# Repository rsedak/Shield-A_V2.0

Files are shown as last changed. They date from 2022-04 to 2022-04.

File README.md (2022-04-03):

[Croatian version](README_HR-HR.md). 

Introduction
============

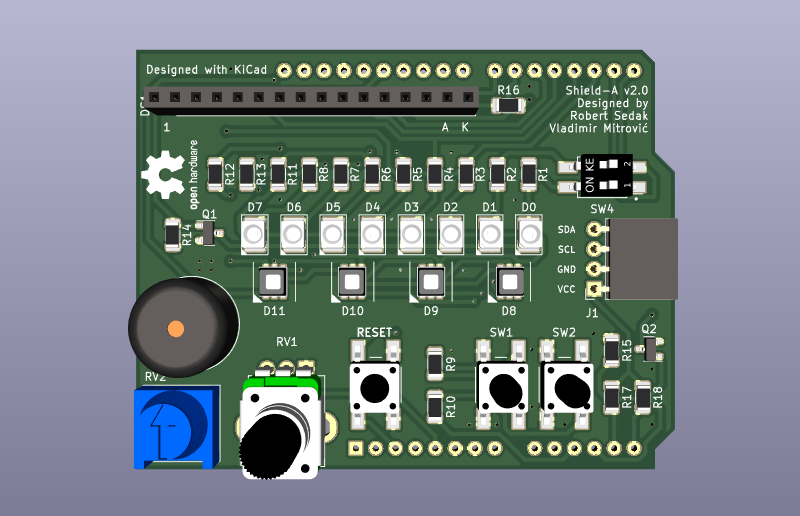
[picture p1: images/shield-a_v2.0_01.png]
Shield application

Shield-A v2.0 is version of Arduino Uno based shield for student education compatible with BASCOM-AVR(C) and Arduino IDE.
During programming please keep in mind next design rules:
- D0-D7 — LEDs can be used only if D12 is set to OUTPUT HIGH state
- LCD 1602 — can be used only if A3 is set to OUTPUT HIGH state
- RGB LED — are connected in matrix (D5-D7 - colors; D8-D11 - LEDs)
- D12 — enables D0-D7 LEDs
- D13 — reserved for buzzer
- A0 — reserved for potentiometer
- A1,A2 — reserved for switch in INPUT_PULLUP mode
- A3 — enables LCD 1602 back-light
- A4,A5 — reserved for I2C communication with on board pull-up resistors

Contributors
------------
- Vladimir Mitrović — features, BASCOM-AVR expertise
- Robert Sedak — features, Arduino expertise, schematic design, CAD design. 

Application
-----------
Robert Sedak made a video with examples programmed in Arduino IDE:

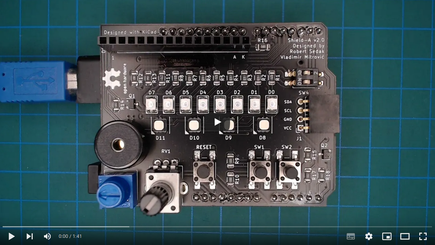
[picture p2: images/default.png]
Shield application (https://youtu.be/8LH1n_c-9tc "Shield-A examples")


You can download examples for Arduino IDE from [here](examples/). 
Examples which name ends with '_R' are solution with register maniputalion.

Bill Of Materials
-----------------
- 1 ea., PCB
- 8 ea., 8.2K ohm 1/4W 1% Resistor 1206 (R1-R8)
- 2 ea., 100 ohm 1/4W 1% Resistor 1206 (R9, R10)
- 1 ea., 2.7K ohm 1/4W 1% Resistor 1206 (R11)
- 1 ea., 1.8K ohm 1/4W 1% Resistor 1206 (R12)
- 1 ea., 3.9K ohm 1/4W 1% Resistor 1206 (R13)
- 4 ea., 10K ohm 1/4W 1% Resistor 1206 (R14, R15, R17, R18)
- 1 ea., 18 ohm 1/4W 1% Resistor 1206 (R16)
- 8 ea., LED 3528 (D0-D7)
- 4 ea., RGB LED RS-3535MWAR (D8-D11)
- 1 ea., 14x7.5mm passive electronic piezoelectric buzzer SE
- 2 ea., MOSFET MMBF170 SOT-23
- 1 ea., 3386-P 10K potentiometer with knob
- 1 ea., RV09 10K potentiometer - long shaft
- 1 ea., 2.54mm pitch slide DIP switch 2-bit
- 1 ea., 6x6x4.3mm SPST Momentary push switch
- 2 ea., 6x6x10mm SPST Momentary push switch
- 1 ea., 1x16Pin 2.54mm Straight Pin Header - Black
- 1 ea., 1x10Pin 2.54mm Straight Pin Header - Black
- 2 ea., 1x8Pin 2.54mm Straight Pin Header - Black
- 1 ea., 1x6Pin 2.54mm Straight Pin Header - Black
- 1 ea., 1x4 pin 2.54mm Socket Connector
- 1 ea., 1x16 pin 2.54mm Socket Connector
- 1 ea., LCD 1602 HD44780 (pin 15 is anode, pin 16 is katode)

Design Files
------------
This project is designed using Open Source [KiCad](http://kicad.org/). Design files are located in the [design_files](design_files/) folder.  You can see the [schematic](images/shield-a_schematic.png).

Gerber files
------------
You can download gerber files from [here](gerber/shield_a_v2.0.zip).

Firmware
--------
This project can be programmed using the Open Source [Arduino](https://www.arduino.cc/) and [BASCOM-AVR(C)](https://www.mcselec.com/index.php?option=com_content&task=view&id=14&Itemid=103).
Arduino examples are located in [examples](examples/) folder.

License
-------
[Attribution-ShareAlike 4.0 International (CC BY-SA 4.0)](https://creativecommons.org/licenses/by-sa/4.0/)

You are free to:
- Share — copy and redistribute the material in any medium or format
- Adapt — remix, transform, and build upon the material

This license is acceptable for Free Cultural Works.
- The licensor cannot revoke these freedoms as long as you follow the license terms.

Under the following terms:
- Attribution — You must give appropriate credit, provide a link to the license, and indicate if changes were made. You may do so in any reasonable manner, but not in any way that suggests the licensor endorses you or your use.
- ShareAlike — If you remix, transform, or build upon the material, you must distribute your contributions under the same license as the original.

No additional restrictions — You may not apply legal terms or technological measures that legally restrict others from doing anything the license permits.

Reference Designs ARE PROVIDED "AS IS" AND "WITH ALL FAULTS". Authors DISCLAIMS ALL OTHER WARRANTIES, EXPRESS OR IMPLIED, REGARDING PRODUCTS, INCLUDING BUT NOT LIMITED TO, ANY IMPLIED WARRANTIES OF MERCHANTABILITY OR FITNESS FOR A PARTICULAR PURPOSE.
Authors may make changes to specifications and product descriptions at any time, without notice. The Customer must notrely on the absence or characteristics of any features or instructions marked "reserved" or "undefined." 
Authors reservesthese for future definition and shall have no responsibility whatsoever for conflicts or incompatibilities arising from future changes to them. The product information on the Web Site or Materials is subject to change without notice. Do not finalize a design with this info.

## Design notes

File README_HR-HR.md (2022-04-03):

[Engleska verzija](README.md). 

Uvod
============
Shield application
Shield-A v2.0 je učilo za programiranje mikropravljača Arduino Uno kompatibilno s BASCOM-AVR(C) i Arduino IDE.
Tijekom programiranja pridržavajte se sljedećih pravila:
- D0-D7 — LE diode se mogu koristiti samo kada je pin D12 postavljen u stanje OUTPUT HIGH
- LCD 1602 — se može koristiti samo ako je pin A3 postavljen u stanje OUTPUT HIGH
- RGB LE diode — su spojene u matricu (D5-D7 - boje; D8-D11 - LE diode)
- D12 — omogućuje korištenje D0-D7 LE diode
- D13 — je rezerviran za pasivnu piezo zujalicu
- A0 — je rezerviran za potenciometar
- A1,A2 — su rezervirani za tipkala u načinu rada INPUT_PULLUP
- A3 — omogućuje pozadinsko osvjetljenje za LCD 1602
- A4,A5 — su rezervirani za komunikaciju preko I2C protokola, pull-up otpornici su na pločici

Autori
------------
- Vladimir Mitrović — svojstva, prilagodba za BASCOM-AVR
- Robert Sedak — svojstva, prilagodba za Arduino, dizajn el. scheme, CAD dizajn. 

Application
-----------
Robert Sedak je snimio video s nekoliko primjera programiranim u Arduino IDE:

Shield application (https://youtu.be/8LH1n_c-9tc "Shield-A examples")

Primjere za Arduino IDE možete preuzati [ovdje](examples/). 
Primjeri koji završavaju na '_R' su rješenja u kojima se koristi upravljanje registrima.

Popis komponenti
-----------------
- 1 ea., PCB
- 8 ea., 8.2K ohm 1/4W 1% otpornik 1206 (R1-R8)
- 2 ea., 100 ohm 1/4W 1% otpornik 1206 (R9, R10)
- 1 ea., 2.7K ohm 1/4W 1% otpornik 1206 (R11)
- 1 ea., 1.8K ohm 1/4W 1% otpornik 1206 (R12)
- 1 ea., 3.9K ohm 1/4W 1% otpornik 1206 (R13)
- 4 ea., 10K ohm 1/4W 1% otpornik 1206 (R14, R15, R17, R18)
- 1 ea., 18 ohm 1/4W 1% otpornik 1206 (R16)
- 8 ea., LED 3528 (D0-D7)
- 4 ea., RGB LED RS-3535MWAR (D8-D11)
- 1 ea., 14x7.5mm pasivna elektronička piezoe zujalica
- 2 ea., MOSFET MMBF170 SOT-23
- 1 ea., 3386-P 10K potenciometer s gumbom
- 1 ea., RV09 10K potenciometer - dugačka osovina
- 1 ea., 2.54mm pitch DIP prekidač 2-bit
- 1 ea., 6x6x4.3mm SPST tipkalo
- 2 ea., 6x6x10mm SPST tipkalo
- 1 ea., 1x16 pin 2.54mm Pin Header
- 1 ea., 1x10 pin 2.54mm Pin Header
- 2 ea., 1x8 pin 2.54mm Pin Header
- 1 ea., 1x6 pin 2.54mm Pin Header
- 1 ea., 1x4 pin 2.54mm utičnica
- 1 ea., 1x16 pin 2.54mm utičnica
- 1 ea., LCD 1602 HD44780 (pin 15 je anoda, pin 16 katoda)

Datoteke s dizajnom
------------
Ovo učilo je dizajnirano pomoću programa [KiCad](http://kicad.org/). Datoteke se nalaze u mapi [design_files](design_files/). Elekroničku schemu možete pogledati [ovdje](images/shield-a_schematic.png).

Gerber datoteke
------------
Gerber datoteke možete preuzeti [ovdje](gerber/shield_a_v2.0.zip).

Firmware
--------
Ovo učilo može biti progrmairano pomoću [Arduino IDE](https://www.arduino.cc/) i [BASCOM-AVR(C)](https://www.mcselec.com/index.php?option=com_content&task=view&id=14&Itemid=103).
Primjeri za Arduino IDS se nalaze u mapi [examples](examples/).

Licenca
-------
[Imenovanje-Dijeli pod istim uvjetima 4.0 međunarodna (CC BY-SA 4.0)](https://creativecommons.org/licenses/by-sa/4.0/deed.hr)

Slobodno možete:
- Dijelite dalje — možete umnažati i redistribuirati materijal u bilo kojem mediju ili formatu
-  Stvarajte prerade — možete remiksirati, mijenjati i prerađivati djelo u bilo koju svrhu, pa i komercijalnu

Davatelj licence ne može opozvati slobode korištenja koje Vam je ponudio dokle god se pridržavate uvjeta licence.

Pod sljedećim uvjetima:
- Imenovanje — Morate adekvatno navesti autora, uvrstiti link na licencu i naznačiti eventualne izmjene. Možete to učiniti na bilo koji razuman način, ali ne smijete sugerirati da davatelj licence izravno podupire Vas ili Vaše korištenje djela. 
- Dijeli pod istim uvjetima — Ako remiksirate, mijenjate ili prerađujete materijal, Vaše prerade morate distribuirati pod istom licencom pod kojom je bio izvornik. 

Bez daljnjih ograničenja — Ne smijete dodavati pravne uvjete ili tehnološke mjere zaštite koji će druge pravno ograničiti da čine ono što im licenca dopušta. 

Odricanje od odgovornosti
-------------------------
NAPOMENA - Dizajn je objavljen u dobroj namjeri i "takav kakav je" ("AS IS"), te sa mogućim greškama. Autori su kreirali učilo, slike, video i programski kod. Nama je radilo i uspjelo raditi na način kako je opisano, što ne znaći da će raditi i Vama. Ne odgovaramo ni za kakve posljedice koje mogu nastati prilikom korištenja učila, uputa ili programskog koda. Odričemo sve odgovorosti i jamstva- sami ste odgovorni za ono što radite i sami ste odgovorni što ste pristali pratiti i koristiti naše upute i informacije. 

Autori mogu mijenjati specifikacije i opise proizvoda u bilo kojem trenutku, bez prethodne obavijesti. Korisnik se ne smije osloniti na odsutnost ili karakteristike bilo kojih značajki ili uputa označenih kao "rezervirano" ili "nedefinirano".
Autori zadržavaju pravo budućih izmjena definicija i neće snositi nikakvu odgovornost za sukobe ili nekompatibilnosti koje proizlaze iz budućih promjena. Podaci o proizvodu na web stranici ili materijalima podložni su promjenama bez prethodne obavijesti. Nemojte finalizirati dizajn s ovim podacima. 

Reference Designs ARE PROVIDED "AS IS" AND "WITH ALL FAULTS". Authors DISCLAIMS ALL OTHER WARRANTIES, EXPRESS OR IMPLIED, REGARDING PRODUCTS, INCLUDING BUT NOT LIMITED TO, ANY IMPLIED WARRANTIES OF MERCHANTABILITY OR FITNESS FOR A PARTICULAR PURPOSE.
Authors may make changes to specifications and product descriptions at any time, without notice. The Customer must notrely on the absence or characteristics of any features or instructions marked "reserved" or "undefined." 
Authors reservesthese for future definition and shall have no responsibility whatsoever for conflicts or incompatibilities arising from future changes to them. The product information on the Web Site or Materials is subject to change without notice. Do not finalize a design with this info.

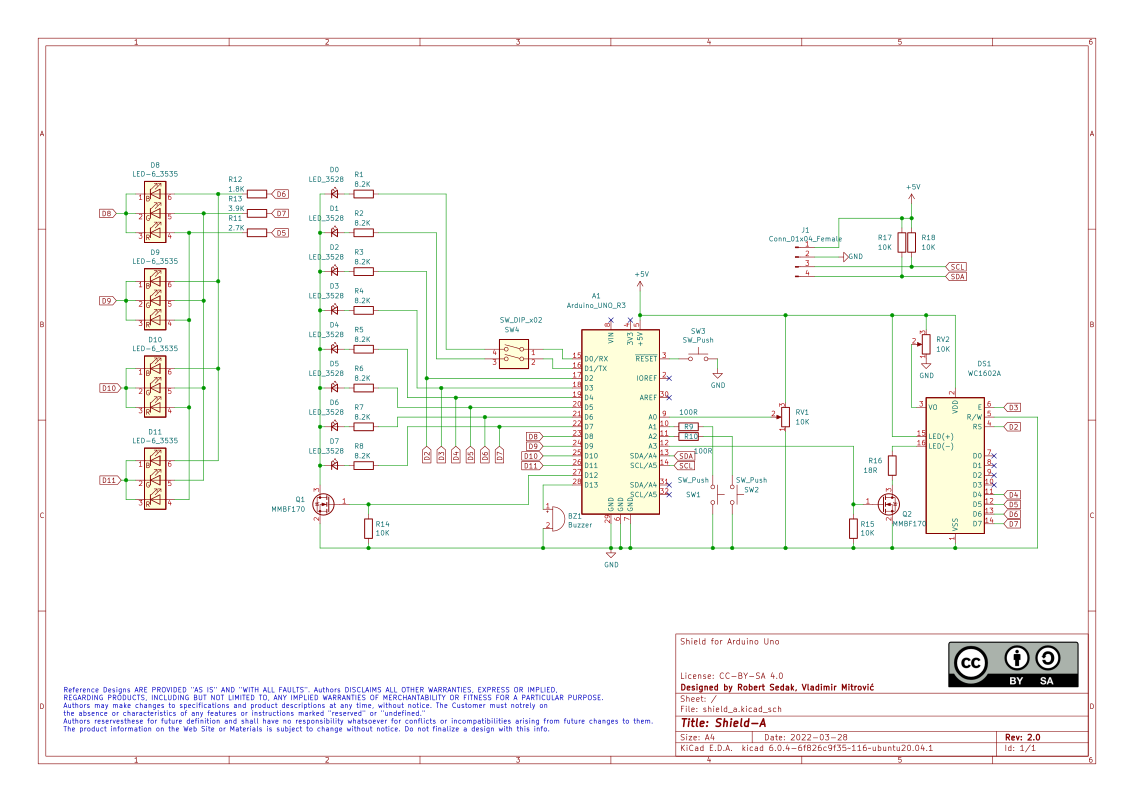
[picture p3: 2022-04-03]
images/shield-a_schematic.png

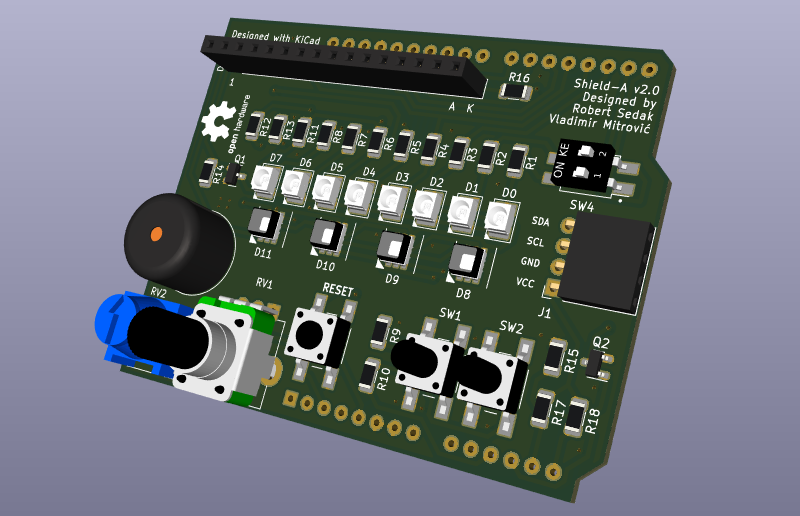
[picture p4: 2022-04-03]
images/shield-a_v2.0_03.png

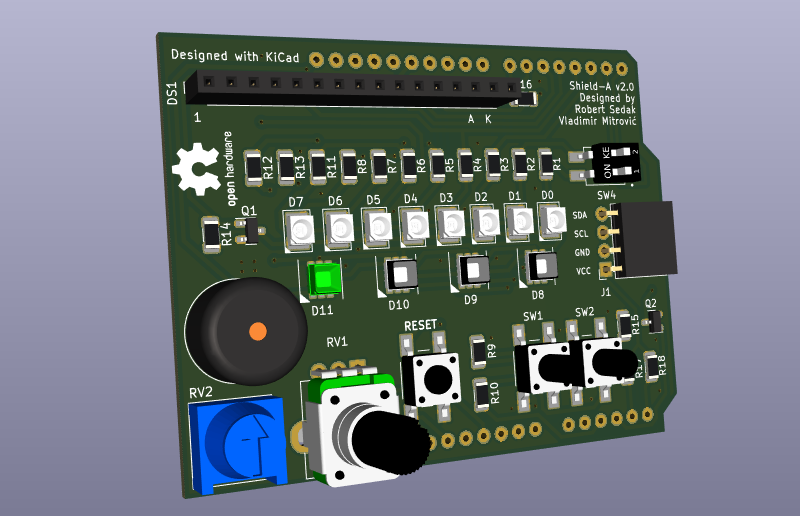
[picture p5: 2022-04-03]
images/shield-a_v2.0_02.png

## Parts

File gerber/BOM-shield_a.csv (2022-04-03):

Comment | Designator | Footprint | LCSC
SW_DIP_x02 | SW4 | SW_DIP_SPSTx02_Slide_Dungguan-Guangzhu-Industrial_DIS02LSGET_W6.0mm_P2.54mm | C54949
SW_Push | SW1,SW2 | SW_SMD_PUSH_6mm_h7mm | C780516
LED-6_3535 | D10,D11,D8,D9 | RS-3535MWAR | C110402
MMBF170 | Q1,Q2 | SOT-23 | C130879
3.9K | R13 | R_1206_3216Metric | C17883
100R | R10,R9 | R_1206_3216Metric | C17901
10K | R14,R15,R17,R18 | R_1206_3216Metric | C17902
18R | R16 | R_1206_3216Metric | C17922
2.7K | R11 | R_1206_3216Metric | C17950
8.2K | R1,R2,R3,R4,R5,R6,R7,R8 | R_1206_3216Metric | C18027
1.8K | R12 | R_1206_3216Metric | C22108
LED_3528 | D0,D1,D2,D3,D4,D5,D6,D7 | LED_3528_Hubei_Kento_Elec | C2308
SW_Push | SW3 | SW_SMD_PUSH_6mm_h4.3mm | C780510

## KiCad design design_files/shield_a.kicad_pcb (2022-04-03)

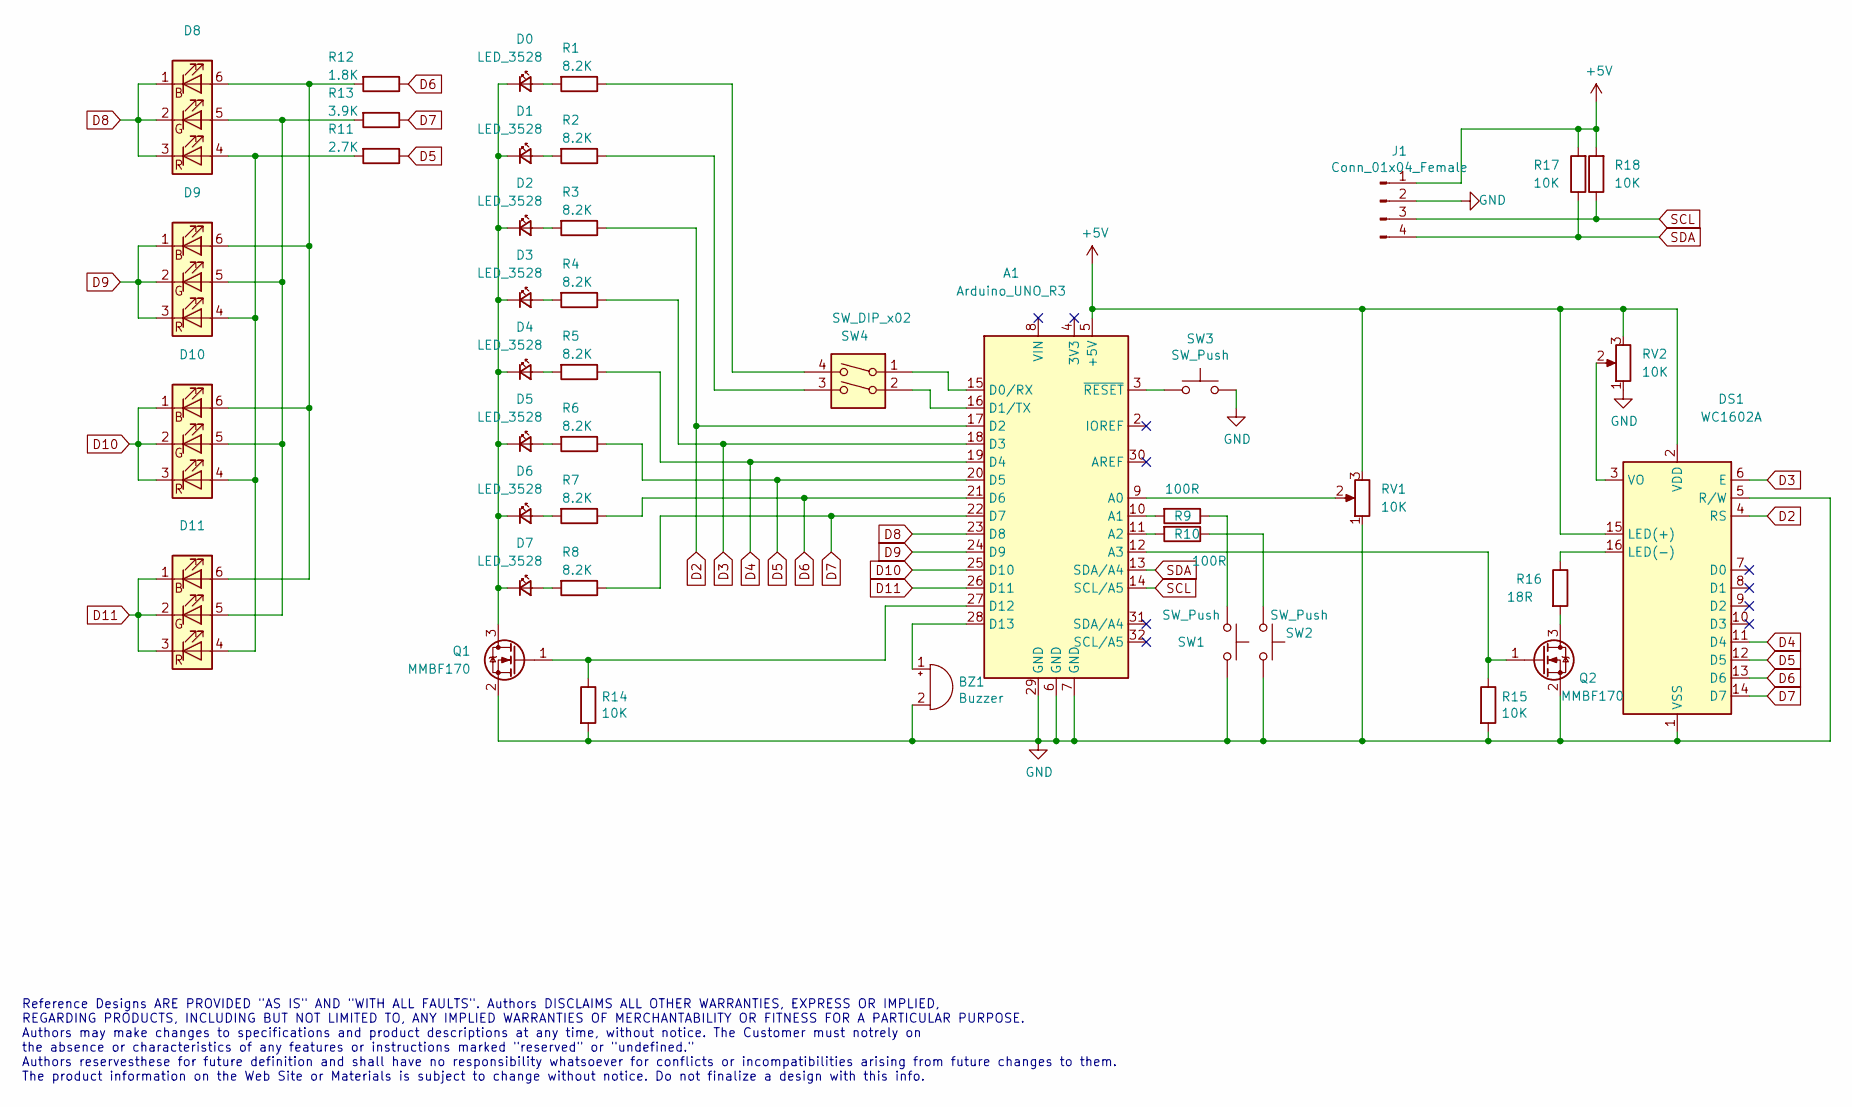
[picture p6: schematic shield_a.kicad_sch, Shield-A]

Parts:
A1: Arduino_UNO_R3
BZ1: Buzzer; Buzzer_12x9.5RM7.6_5; LCSC C417411
D0, D1, D2, D3, D4, D5, D6, D7: LED_3528; LED_3528_Hubei_Kento_Elec; LCSC C2308
D8, D9, D10, D11: LCSC C110402
DS1: WC1602A; PinSocket_1x16_P2.54mm_Vertical; LCSC C66987
J1: Conn_01x04_Female; PinSocket_1x04_P2.54mm_Horizontal; LCSC C225512
Q1, Q2: MMBF170; SOT-23; LCSC C130879
R1, R2, R3, R4, R5, R6, R8: 8.2K; R_1206_3216Metric; LCSC C18027
R7: 8.2K; R_1206_3216Metric; JLC 1206
R9, R10: 100R; R_1206_3216Metric; LCSC C17901
R11: 2.7K; R_1206_3216Metric; LCSC C17950
R12: 1.8K; R_1206_3216Metric; LCSC C22108
R13: 3.9K; R_1206_3216Metric; LCSC C17883
R14, R15, R17, R18: 10K; R_1206_3216Metric; LCSC C17902
R16: 18R; R_1206_3216Metric; LCSC C17922
RV1: 10K; Potentiometer_Alpha_RV09ACF-40_Single_Vertical; LCSC C209779
RV2: 10K; Potentiometer_Bourns_3386P_Vertical; LCSC C330455
SW1, SW2: SW_Push; SW_SMD_PUSH_6mm_h7mm; LCSC C780516
SW3: SW_Push; SW_SMD_PUSH_6mm_h4.3mm; LCSC C780510
SW4: SW_DIP_x02; SW_DIP_SPSTx02_Slide_Dungguan-Guangzhu-Industrial_DIS02LSGE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; LCSC C54949

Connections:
+5V: A1.5 (+5V), DS1.2 (VDD), DS1.15 (LED(+)), J1.1, R17.2, R18.2, RV1.3, RV2.3
D2: A1.17 (D2), DS1.4 (RS), R3.1
D3: A1.18 (D3), DS1.6 (E), R4.1
D4: A1.19 (D4), DS1.11 (D4), R5.1
D5: A1.20 (D5), DS1.12 (D5), R6.1, R11.1
D6: A1.21 (D6), DS1.13 (D6), R7.1, R12.1
D7: A1.22 (D7), DS1.14 (D7), R8.1, R13.1
D8: A1.23 (D8), D8.1 (BK), D8.2 (GK), D8.3 (RK)
D9: A1.24 (D9), D9.1 (BK), D9.2 (GK), D9.3 (RK)
D10: A1.25 (D10), D10.1 (BK), D10.2 (GK), D10.3 (RK)
D11: A1.26 (D11), D11.1 (BK), D11.2 (GK), D11.3 (RK)
GND: A1.6 (GND), A1.7 (GND), A1.29 (GND), BZ1.2 (+), DS1.1 (VSS), DS1.5 (R/W), J1.2, Q1.2 (S), Q2.2 (S), R14.2, R15.2, RV1.1, RV2.1, SW1.2, SW2.2, SW3.2
unnamed: A1.3 (~RESET), SW3.1
unnamed: A1.9 (A0), RV1.2
unnamed: A1.10 (A1), R9.2
unnamed: A1.11 (A2), R10.2
unnamed: A1.12 (A3), Q2.1 (G), R15.1
unnamed: A1.15 (D0/RX), SW4.1
unnamed: A1.16 (D1/TX), SW4.2
unnamed: A1.27 (D12), Q1.1 (G), R14.1
unnamed: A1.28 (D13), BZ1.1 (-)
unnamed: D0.1 (K), D1.1 (K), D2.1 (K), D3.1 (K), D4.1 (K), D5.1 (K), D6.1 (K), D7.1 (K), Q1.3 (D)
unnamed: D0.2 (A), R1.2
unnamed: D1.2 (A), R2.2
unnamed: D2.2 (A), R3.2
unnamed: D3.2 (A), R4.2
unnamed: D4.2 (A), R5.2
unnamed: D5.2 (A), R6.2
unnamed: D6.2 (A), R7.2
unnamed: D7.2 (A), R8.2
unnamed: D8.4 (RA), D9.4 (RA), D10.4 (RA), D11.4 (RA), R11.2
unnamed: D8.5 (GA), D9.5 (GA), D10.5 (GA), D11.5 (GA), R13.2
unnamed: D8.6 (BA), D9.6 (BA), D10.6 (BA), D11.6 (BA), R12.2
unnamed: DS1.3 (VO), RV2.2
unnamed: DS1.16 (LED(-)), R16.1
unnamed: Q2.3 (D), R16.2
unnamed: R1.1, SW4.4
unnamed: R2.1, SW4.3
unnamed: R9.1, SW1.1
unnamed: R10.1, SW2.1
SCL: A1.14 (SCL/A5), J1.3, R18.1
SDA: A1.13 (SDA/A4), J1.4, R17.1

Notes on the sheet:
Reference Designs ARE PROVIDED "AS IS" AND "WITH ALL FAULTS". Authors DISCLAIMS ALL OTHER WARRANTIES, EXPRESS OR IMPLIED, REGARDING PRODUCTS, INCLUDING BUT NOT LIMITED TO, ANY IMPLIED WARRANTIES OF MERCHANTABILITY OR FITNESS FOR A PARTICULAR PURPOSE. Authors may make changes to specifications and p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

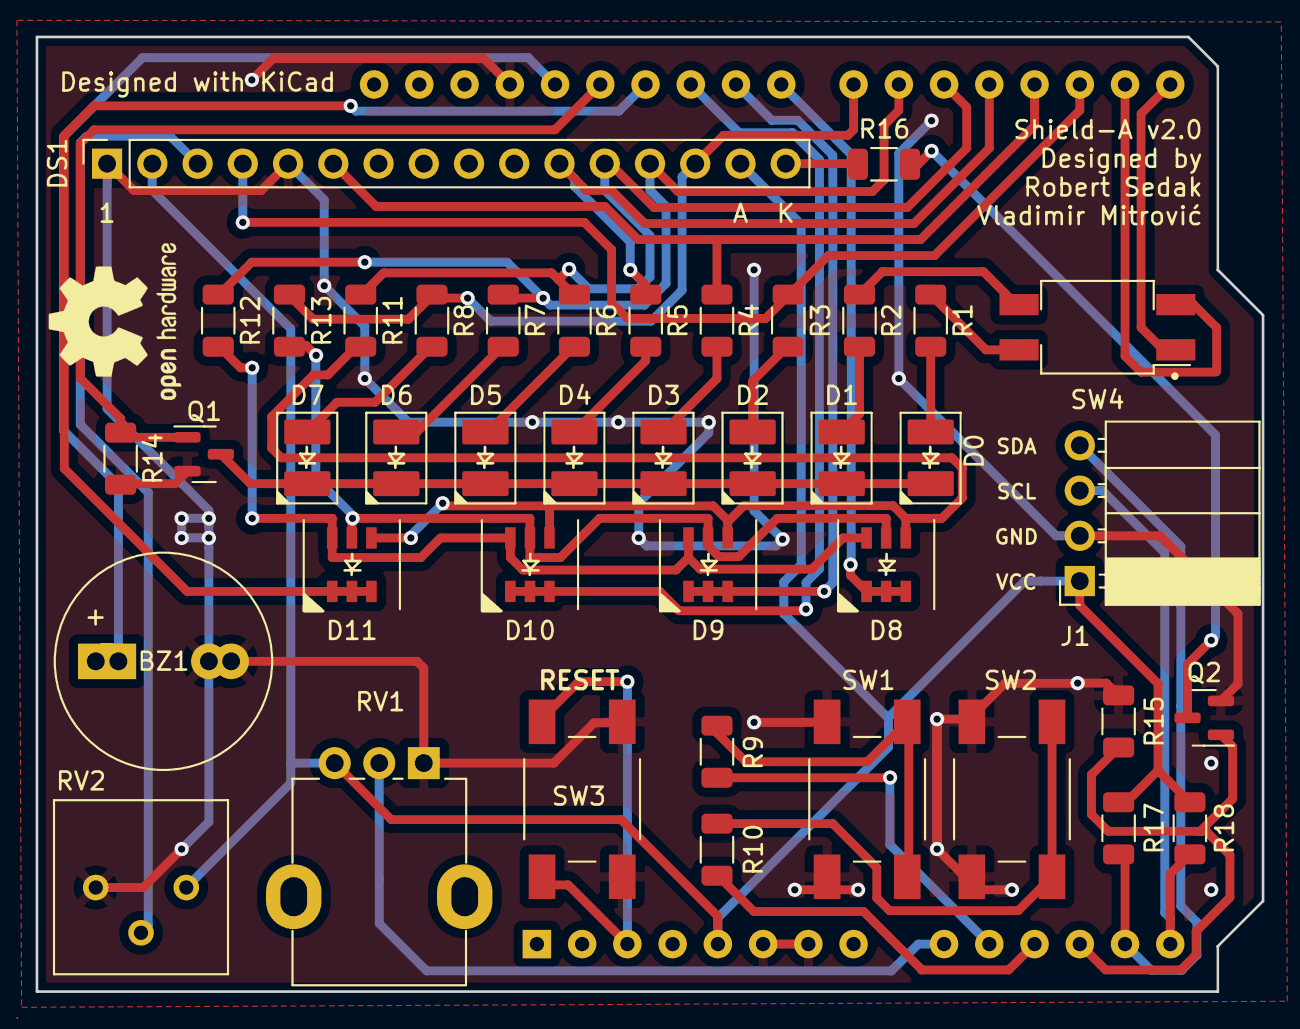
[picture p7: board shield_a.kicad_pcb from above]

Board: 2 copper layers, 68.8 x 53.6 mm, 42 parts (1 on the bottom side), 42 nets.

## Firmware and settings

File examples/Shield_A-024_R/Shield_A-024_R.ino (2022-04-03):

/* RGB matrix 
 * multiplexing four RGB LED
 * with register manipulation  
 * 
 * Arduino Digital Pin | Register Pin Mark
 * ----------------------------------------
 *                   0 | PD0 
 *                   1 | PD1 
 *                   2 | PD2 
 *                   3 | PD3
 *                   4 | PD4
 *                   5 | PD5
 *                   6 | PD6
 *                   7 | PD7
 *                   8 | PB0
 *                   9 | PB1
 *                  10 | PB2
 *                  11 | PB3
 *                  12 | PB4
 *                  13 | PB5 
 * 
 * Created 2019 by Robert Sedak
 * 
 * This example code is in the public domain.
 *  
 *  THE SOFTWARE IS PROVIDED "AS IS", WITHOUT WARRANTY OF ANY KIND, 
 *  EXPRESS OR IMPLIED, INCLUDING BUT NOT LIMITED TO THE WARRANTIES 
 *  OF MERCHANTABILITY, FITNESS FOR A PARTICULAR PURPOSE AND 
 *  NONINFRINGEMENT. IN NO EVENT SHALL THE AUTHOR(S) OR 
 *  CONTRIBUTOR(S) BE LIABLE FOR ANY CLAIM, DAMAGES OR OTHER 
 *  LIABILITY, WHETHER IN AN ACTION OF CONTRACT, TORT OR OTHERWISE, 
 *  ARISING FROM, OUT OF OR IN CONNECTION WITH THE SOFTWARE OR 
 *  THE USE OR OTHER DEALINGS IN THE SOFTWARE.
 */

byte D8;
byte D9;
byte D10;
byte D11;
int RGBDelay = 2;  // delay 2ms
unsigned long lastTime = 0;
int randomNumber = 0;

void setup() {

  // Set D5-D7 as output pins 
  DDRD |= ((1 << PD5) | (1 << PD6) | (1 << PD7));

  // Set D8-D11 as output pins 
  DDRB |= ((1 << PB0) | (1 << PB1) | (1 << PB2) | (1 << PB3));
  
  // Turn OFF RED, Blue and Green LED
  PORTD &= ~((1 << PD5) | (1 << PD6) | (1 << PD7));

  // Turn OFF D8, D9, D10 and D11 RGB LED - pins are in HIGH state
  PORTB |= ((1 << PB0) | (1 << PB1) | (1 << PB2) | (1 << PB3));

  // Seed ranodom generator
  randomSeed(analogRead(A6));
} // end of setup function

void loop() {

  // define new random colors for RGB LEDs every second
  // no LED can not have same color
  if ((millis() - lastTime) > 1000) {
    D8 = random(1,8);
    randomNumber = random(1,8);
    while ( D8 == randomNumber ) {
      randomNumber = random(1,8);
    }
    D9 = randomNumber;

    while (    D8 == randomNumber 
            || D9 == randomNumber ) {
      randomNumber = random(1,8);
    }    
    D10 = randomNumber;
    while (    D8 == randomNumber 
            || D9 == randomNumber 
            || D10 == randomNumber) {
      randomNumber = random(1,8);
    }
    D11 = randomNumber;
    lastTime = millis();
  }
  
  PORTB &= ~(1 << PB0);   // Turn ON RGB LED D8
  PORTB |= (1 << PB3);    // Turn OFF RGB LED D11
  PORTD = (D8 << 5);      // Set color defined in variable D8
  
  delay(RGBDelay);

  PORTB |= (1 << PB0);    // Turn OFF RGB LED D8
  PORTB &= ~(1 << PB1);   // Turn ON RGB LED D9
  PORTD = (D9 << 5);      // Set color defined in variable D9
  
  delay(RGBDelay);

  PORTB |= (1 << PB1);   // Turn OFF RGB LED D9
  PORTB &= ~(1 << PB2);  // Turn ON RGB LED D10
  PORTD = (D10 << 5);    // Set color defined in variable D10
  
  delay(RGBDelay);

  PORTB |= (1 << PB2);   // Turn OFF RGB LED D10
  PORTB &= ~(1 << PB3);  // Turn ON RGB LED D11 
  PORTD = (D11 << 5);    // Set color defined in variable D11
  
  delay(RGBDelay);
} // end of loop function

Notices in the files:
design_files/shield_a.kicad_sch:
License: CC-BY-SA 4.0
